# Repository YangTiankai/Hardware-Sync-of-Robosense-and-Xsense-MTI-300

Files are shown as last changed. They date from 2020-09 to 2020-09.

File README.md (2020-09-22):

# Hardware-Sync-of-Robosense-and-Xsense-MTI-300
Robosense雷达和Xsense MTI-300的硬件时间同步方案

本项目主要工作是进行了Robosense雷达和Xsense MTI-300的硬件时间同步

首先明确，需要进行硬件同步的原因是：各个传感器的时间坐标不一致且流速有差异（主要是晶振误差带来的）
因此硬件同步的任务是
1. 使得各个传感器的时间坐标的流速一致
2. 得出各个传感器的时间坐标的差

我们的工作是将IMU和Lidar的时间轴都向IMU对齐

该项目使用了另一个STM32F405核心板，见  
https://github.com/YangTiankai/STM32F4-Core-Board

## 传感器的硬件同步方法
### MTI-300的硬件接口和时间同步方法

MTI-300的接口如下图，其中GND、USB-DP、USB-DM、Vin应当转为USB2.0接口接入电脑，RS232两个引脚不使用，ClockSync、SyncOut、SyncIn为硬件时间同步引脚
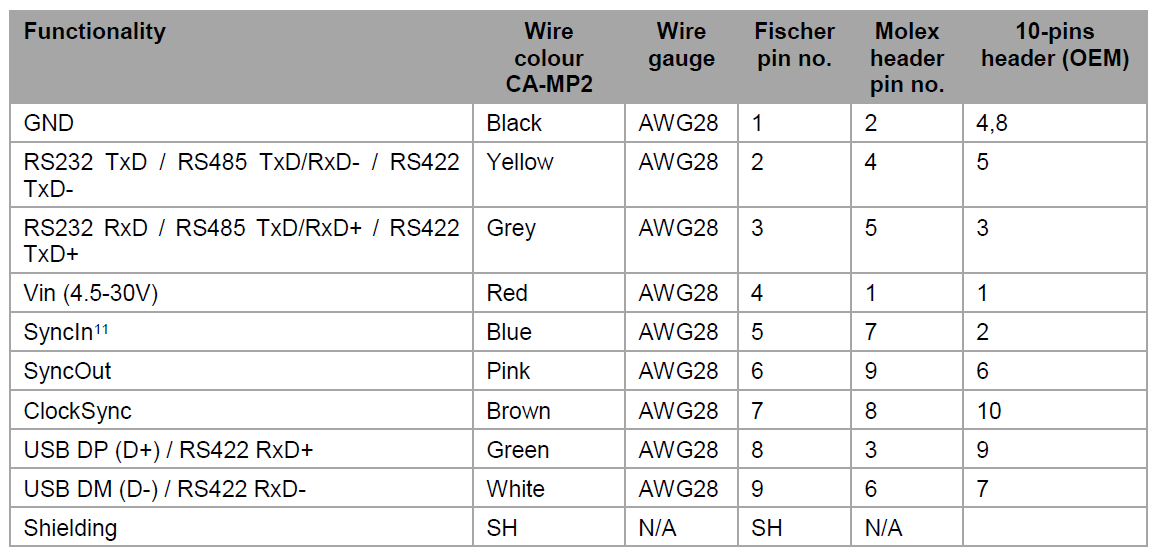
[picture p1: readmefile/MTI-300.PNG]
MTI-300接口线序


MTI-300官网上的硬件时间同步方法，我们只需要使用其中的部分功能  
https://base.xsens.com/hc/en-us/sections/201296842-Algorithms-Data

MTI-300的StartSample功能的官网说明如下  
https://base.xsens.com/hc/en-us/articles/208595729-ClockSync-and-StartSampling

当在上位机中将SyncIn配置为StartSample功能后，MTI-300上电后不会输出数据，直到在SyncIn上检测到一个上升沿  
我们的项目只需要加速度和角速度数据，根据文档和我们实际实验测试，StartSample后大约3ms后会有第一个数据包

MTI-300的SyncOut功能的官网说明如下，可以将其配置为特定频率的脉冲输出  
https://base.xsens.com/hc/en-us/articles/211592185-Synchronization-with-the-MTi

### Robosense激光雷达的时间同步接口
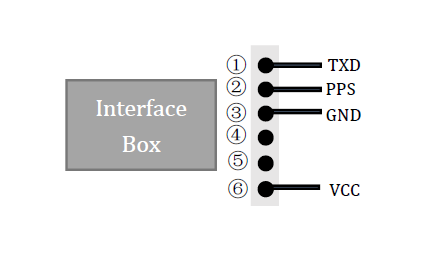
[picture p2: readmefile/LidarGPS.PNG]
Robosense GPS同步接口


该接口是用于将GPS收到的UTC时间同步为雷达内部的时间  
PPS引脚检测的是一个1Hz的方波，每当上升沿到来后，应当向Robosense雷达GPS接口的串口接收RXD引脚发送一个串口包，该串口包是模拟GPS设备的GPRMC规范

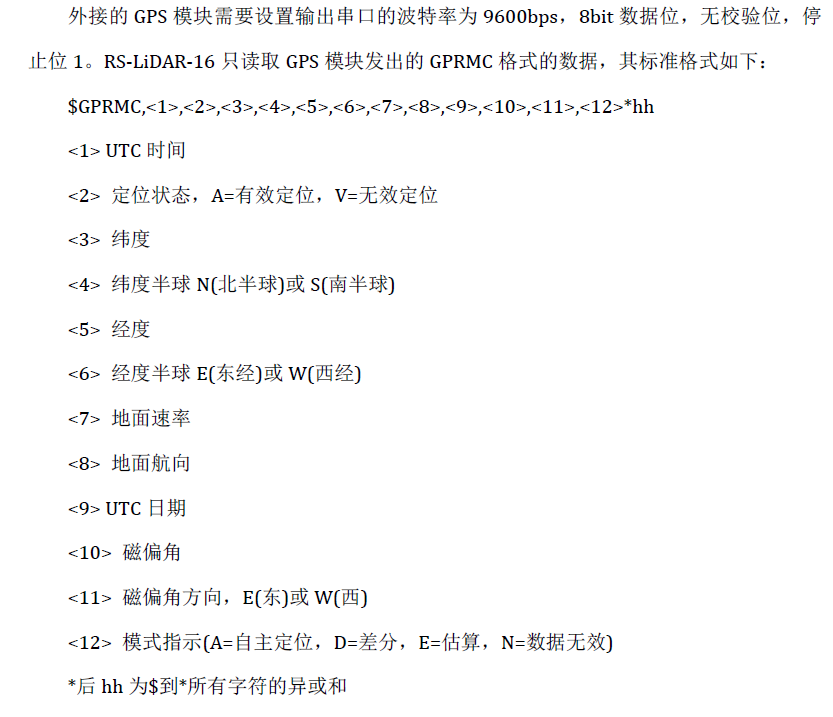
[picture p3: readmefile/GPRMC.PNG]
GPS设备的GPRMC规范


## 系统构成
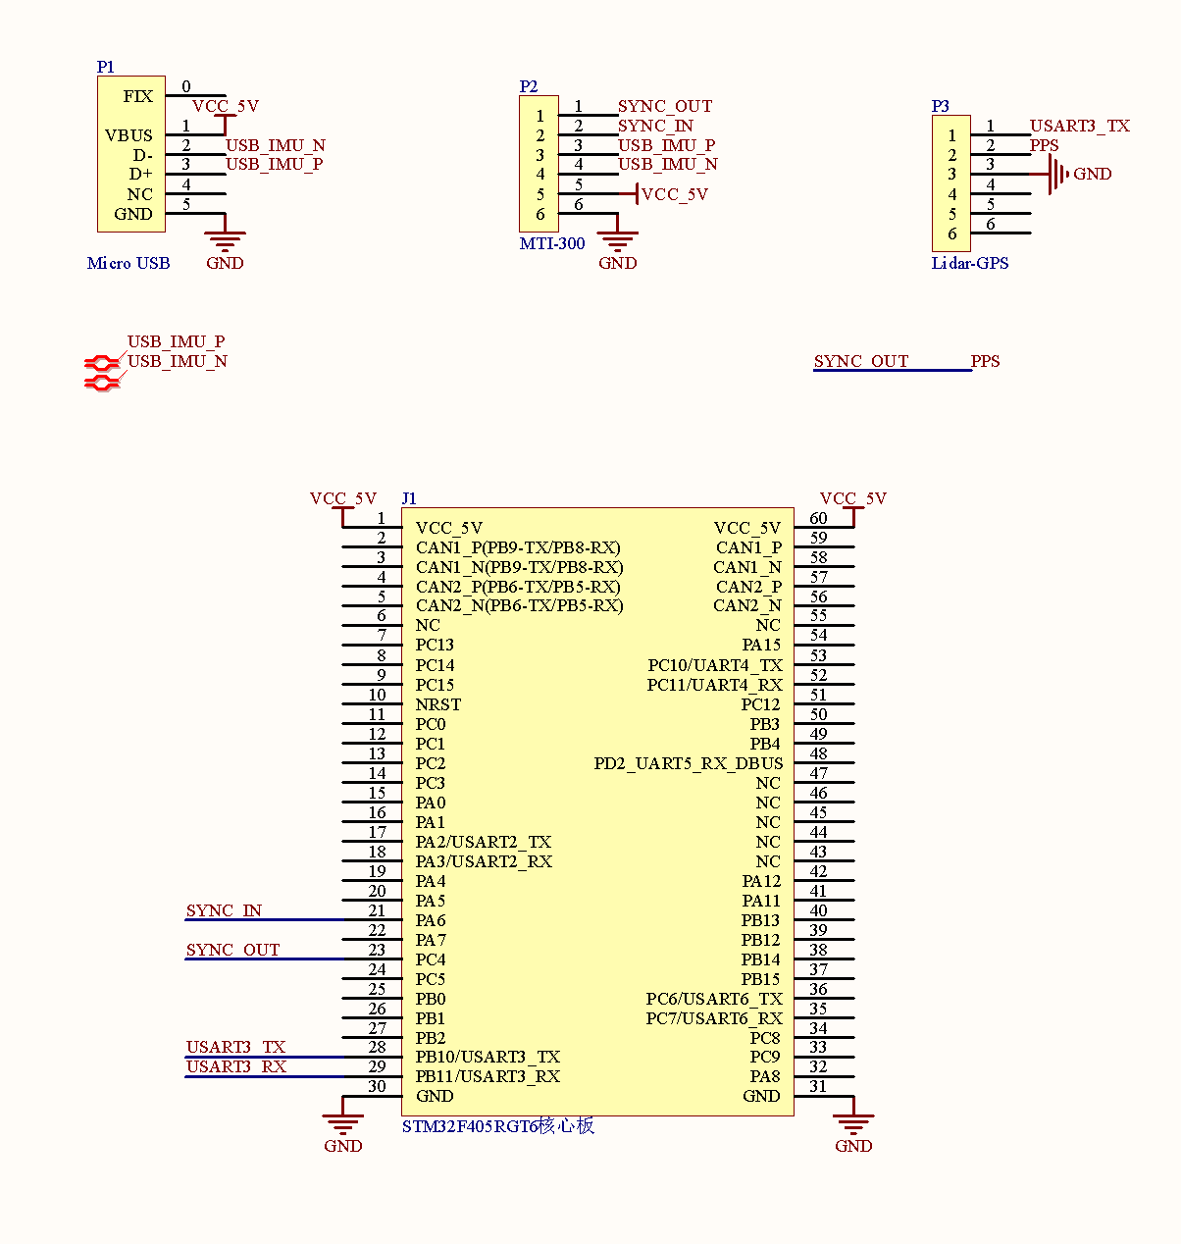
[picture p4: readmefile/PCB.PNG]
PCB原理图


将MTI-300的USB信号转为标准USB接口接入PC  
将MTI300的SyncIn引脚接入stm32的PA引脚  
将MTI-300的SyncOut引脚接入stm32单片机的PC4引脚和雷达GPS接口的PPS引脚  
将stm32的串口发送引脚PB10/USART3_TX接到雷达GPS接口的串口接收引脚TXD  

## 上位机配置
在上位机配置SyncIn引脚为StartSample功能  
在上位机配置MTI-300的SyncOut引脚为脉冲输出功能，将其配置为能够输出频率1Hz，脉宽200ms的矩形波

## 运行时流程
上电后3秒，stm32向SyncIn发出一个StartSapmle脉冲  
将PC引脚配置为上升沿触发的外部中断，当上升沿到来时，将UTC时间通过串口发出，每次自加1秒，第一个数据的时间约定为2020年1月1日0分0秒

## 计算硬件时间差
经过上述的过程，我们已经将雷达的硬件时间流速同步为和IMU一致，现在我们需要推算两者硬件时间戳的差

记stm32的时间轴为t_32，雷达的时间轴为t_li，IMU的时间轴为t_imu

当stm32发出第一个脉冲时，设此时  
t_32 = T0  
t_imu = T1  

SyncOut上出现第一个上升沿时，设此时  
t_32 = T2  
t_li = T3  

可得  
t_li - t_32 = T3 - T2   
t_imu - t_32 = T1 - T0

可得  
t_li - t_imu = T3 - T1 - (T2 - T0)

T3为约定量，为2020年1月1日0分0秒，直接在Lidar回传的时间戳扣除即可  
T1的测量方法为，当PC收到第一个IMU数据包时，将其减去2.69ms即为T1  
根据实验和手册，(T2 - T0)为1000.19ms

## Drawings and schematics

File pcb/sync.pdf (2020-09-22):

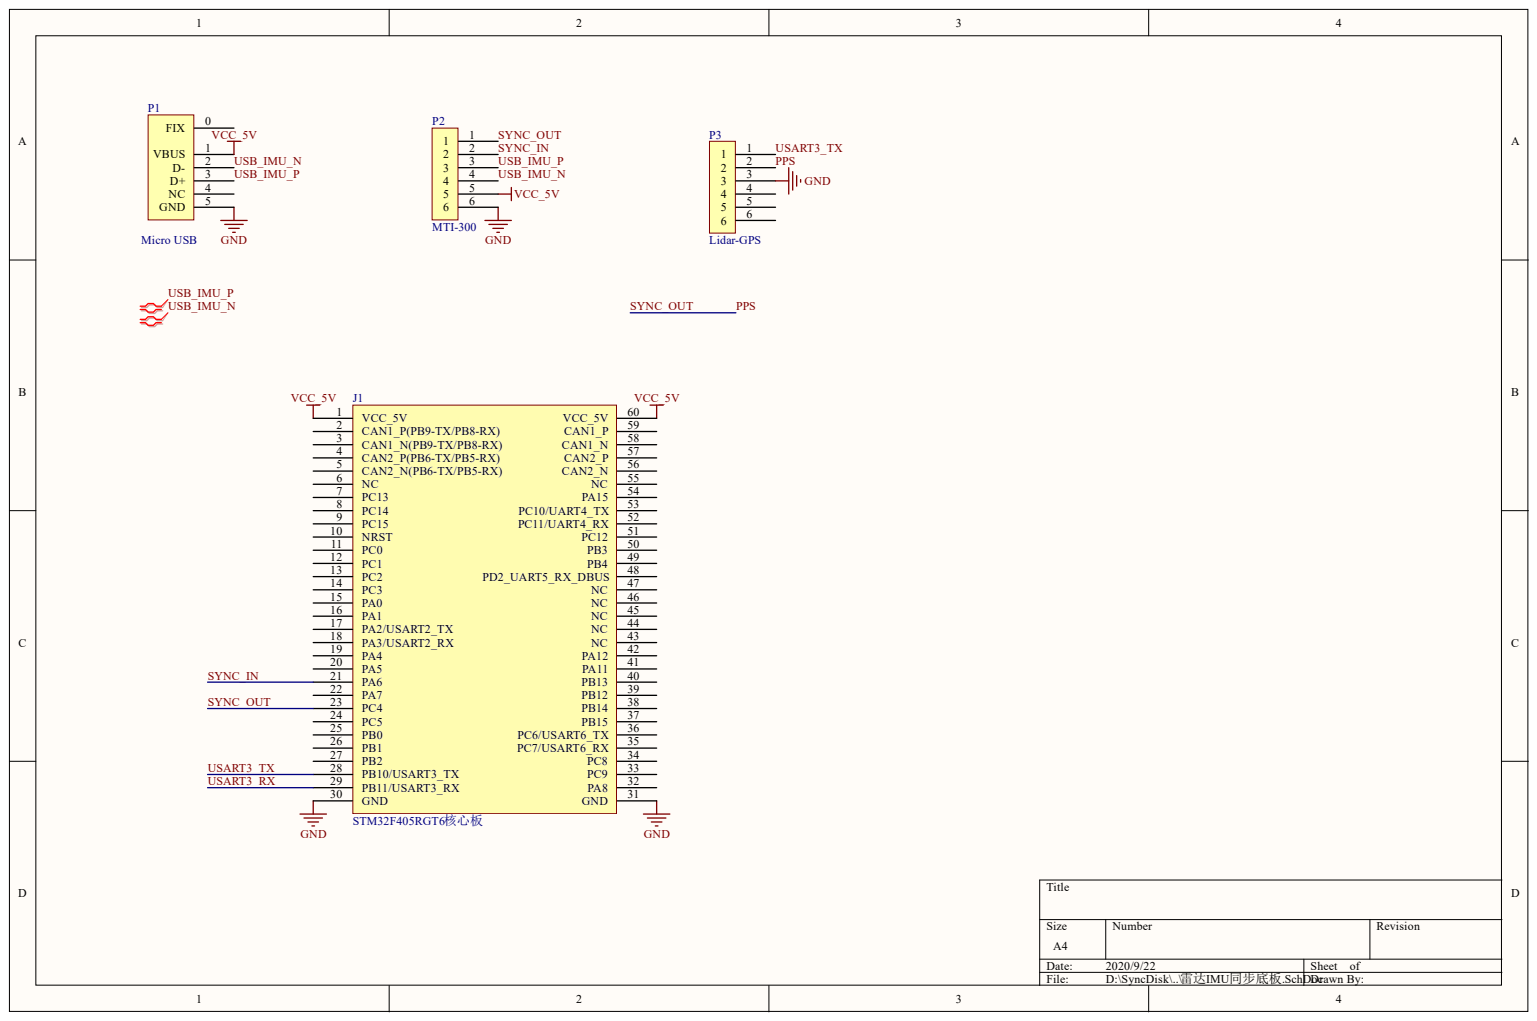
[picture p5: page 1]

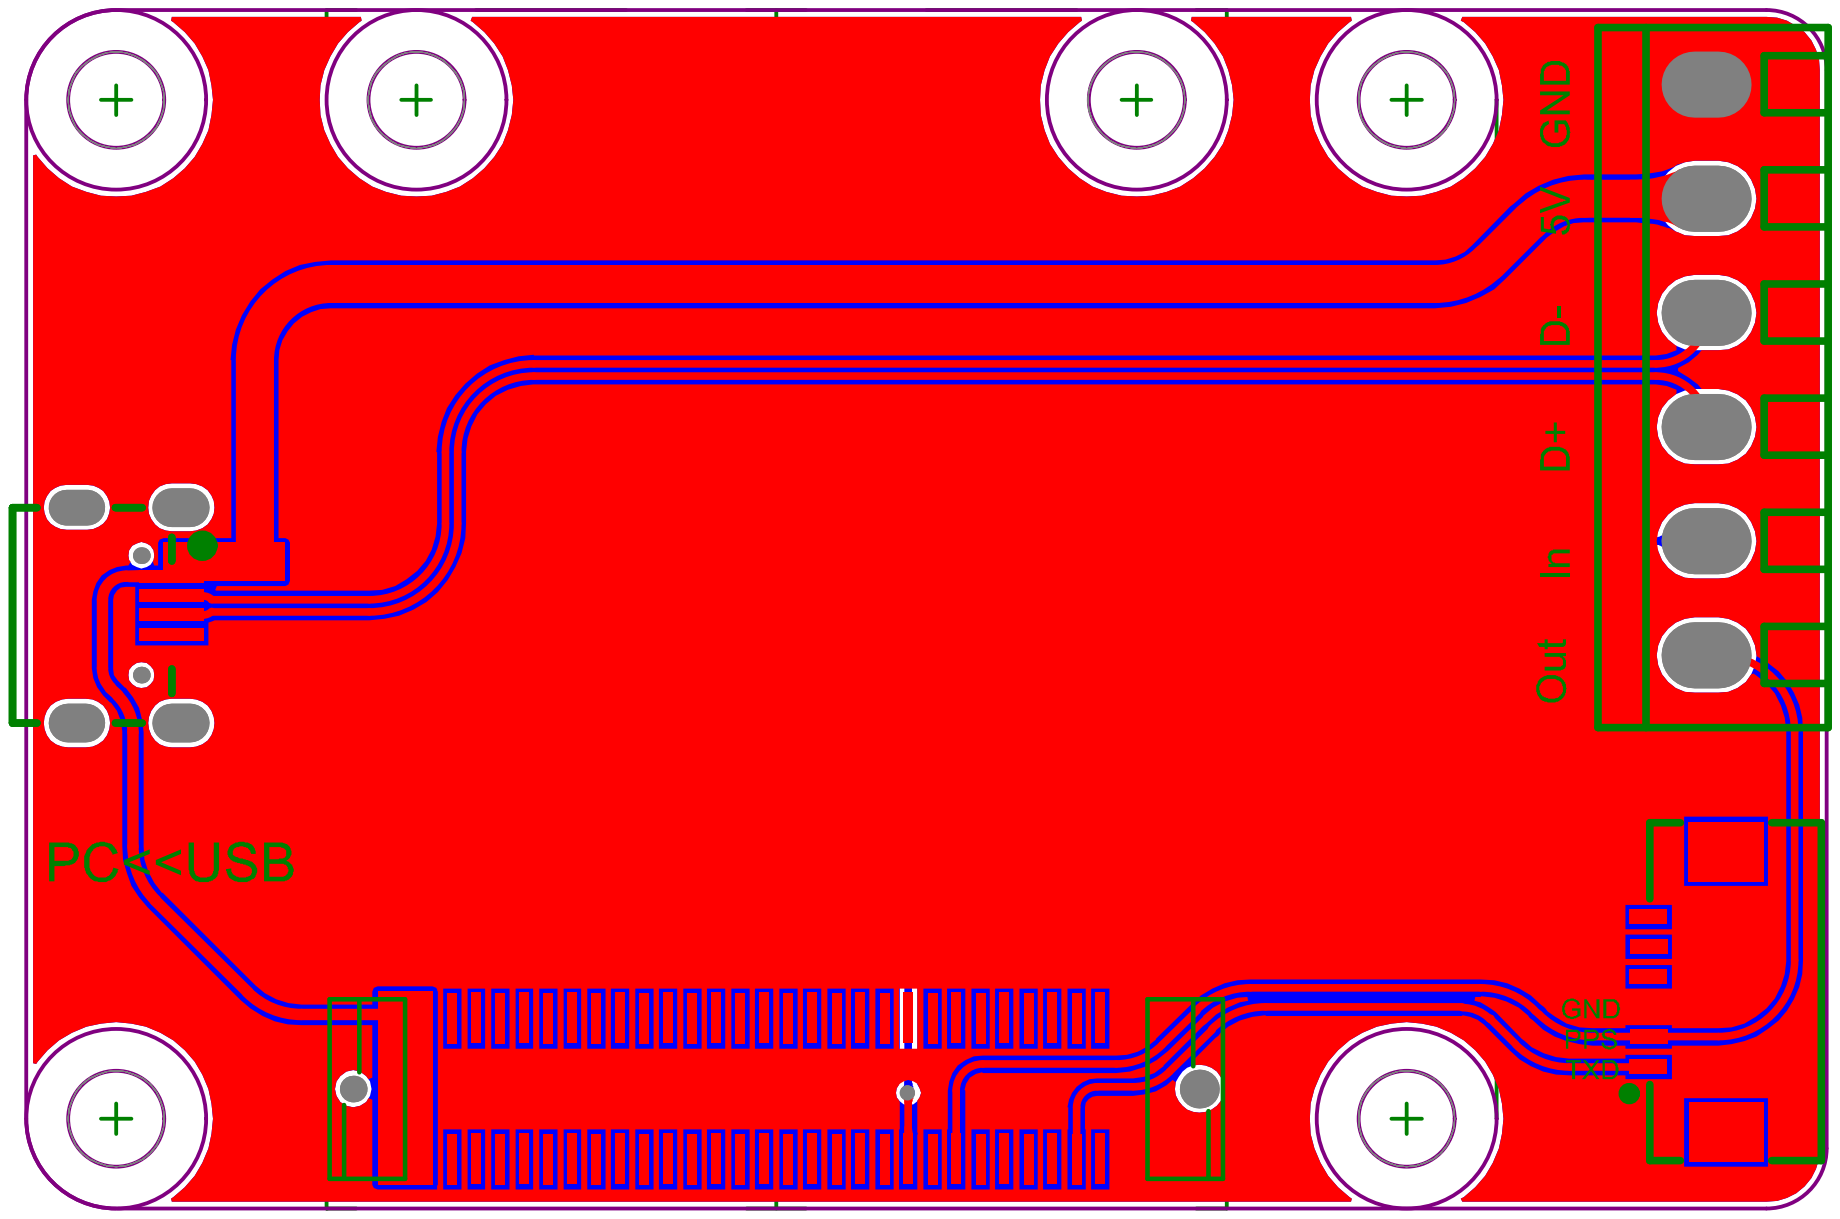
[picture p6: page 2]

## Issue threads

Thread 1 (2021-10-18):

你好，可以交流一下设备同步问题么？

thzhfei, 2021-10-18:
IMU的同步逻辑在官网没看明白。。。

YangTiankai, 2021-10-20:
是官方文档方面的问题吗？

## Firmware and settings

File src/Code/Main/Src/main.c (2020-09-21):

#include "main.h"


uint8_t u5rxdata[UART_DMA_RX_SIZE] = {0};
uint8_t u6rxdata[UART_DMA_RX_SIZE] = {0};
CLOCK clock = {0};
UTC utc = {0};

int rxlen = 0;

int pulse_count = 0;
int sample_us = 0;
int flag_first_sample = 0;
int first_ms = 0;
int first_us = 0;

void MY_UART_IRQHandler(UART_HandleTypeDef *huart)
{
    if(huart->Instance == UART5)
    {
        if(__HAL_UART_GET_FLAG(huart, UART_FLAG_IDLE) != RESET)
        {
            __HAL_UART_CLEAR_IDLEFLAG(huart);
            rxlen = UART_DMA_RX_SIZE - DMA1_Stream0->NDTR;
            HAL_UART_DMAStop(huart);
            HAL_UART_Receive_DMA(huart, u5rxdata, UART_DMA_RX_SIZE);
            if(rxlen == 18)
            {
            }
        }
    }
    else if(huart->Instance == USART6)
    {
        if(__HAL_UART_GET_FLAG(huart, UART_FLAG_IDLE) != RESET)
        {
            __HAL_UART_CLEAR_IDLEFLAG(huart);
   
            HAL_UART_DMAStop(huart);
            HAL_UART_Receive_DMA(huart, u6rxdata, UART_DMA_RX_SIZE);
        }
    }
    
}

void HAL_UART_RxCpltCallback(UART_HandleTypeDef *huart)
{
    if(huart->Instance == UART5)
    {

    }
}

 void HAL_UART_ErrorCallback(UART_HandleTypeDef *huart)
 {
 	if(huart->Instance == USART3)
 	{
        __HAL_UART_CLEAR_OREFLAG(&huart5);
 	}
    else if(huart->Instance == UART5)
 	{
        __HAL_UART_CLEAR_OREFLAG(&huart5);
 	}
 	else if(huart->Instance == USART6)
 	{
        __HAL_UART_CLEAR_OREFLAG(&huart6);
 	}     
 }

inline void MY_SYSCLK_Callback(void)
{

    // clock.cnt_100us++;
    clock.ms++;
    clock.cycle100ms++;
    clock.cycle1000ms++;
    clock.ms_startsample = clock.ms - START_SAMPLE_MS;


}
uint8_t buff[256] = {0};
int len = 0;
void HAL_GPIO_EXTI_Callback(uint16_t GPIO_Pin)
{
    if(GPIO_Pin == GPIO_PIN_4)
    {
        if( (GPIOC->IDR & (1 << 4) ) != 0 ) //如果此时PC3确实是高电平
        {

            if(pulse_count == 0)         
            {
                first_ms = clock.ms;
                first_us = TIM6->CNT;
            }
            pulse_count++;
            inc_sec_utc(&utc);
            genstr_utc(&utc, buff, &len);
            HAL_UART_Transmit(&huart3, buff, len, 0xFFFF);
            // HAL_UART_Transmit(&huart1, buff, len, 0xFFFF);
            // MY_UART_Transmit_DMA(&huart3, buff, len);
        }
    }
}

int main(void)
{    
    init_utc(&utc);

    HAL_Init();
    SystemClock_Config();

    LED_Core_Init();
    MX_GPIO_Init();
    MX_DMA_Init();
    MX_IWDG_Init();
    MX_USART1_UART_Init();  //核心板输出
    // MX_USART2_UART_Init();  //无线串口
    MX_USART3_UART_Init();
    // MX_UART5_Init();        //接收机
    // MX_USART6_UART_Init();  //上位机
    MX_TIM6_Init();
    // MX_TIM3_Init();
    // HAL_UART_Receive_DMA(&huart5, u5rxdata, UART_DMA_RX_SIZE);
    // HAL_UART_Receive_DMA(&huart6, u6rxdata, UART_DMA_RX_SIZE);
    
    while(1)
    {
				
        if (clock.ms == START_SAMPLE_MS)
        {
            if(flag_first_sample == 0)
            {
                GPIOA->BSRR |= 1 << 6;
                sample_us = TIM6->CNT;
                LED_Core_On();
                flag_first_sample = 1;
                printf("a");
            }
        }
        else if (clock.ms == START_SAMPLE_MS + START_SAMPLE_LEN)
        {
            GPIOA->BSRR |= 1 << 22;
        }

        if(clock.cycle100ms >= 100)
        {
            cycle_100ms_callback();
            clock.cycle100ms = 0;            
        }
    }
}



void MY_UART_Transmit_DMA(UART_HandleTypeDef *huart, uint8_t *pData, uint16_t Size)
{
    if(__HAL_DMA_GET_FLAG(huart->hdmatx, DMA_FLAG_TCIF2_6) == RESET)
    {
        huart->hdmatx->Instance->CR &= (uint32_t)(~DMA_SxCR_DBM);
        huart->hdmatx->Instance->NDTR = Size;
        huart->hdmatx->Instance->M0AR = (uint32_t)pData;        
        huart->hdmatx->Instance->PAR = (uint32_t)(&huart->Instance->DR);        
        __HAL_DMA_ENABLE(huart->hdmatx);
        __HAL_UART_CLEAR_FLAG(huart, UART_FLAG_TC);

    }
    else
    {
        __HAL_DMA_CLEAR_FLAG(huart->hdmatx, DMA_FLAG_TCIF2_6);
        __HAL_DMA_DISABLE(huart->hdmatx);
    }
}


inline void cycle_100ms_callback(void)
{
    // LED_Core_Turn();
    HAL_IWDG_Refresh(&hiwdg);
    return;
}
